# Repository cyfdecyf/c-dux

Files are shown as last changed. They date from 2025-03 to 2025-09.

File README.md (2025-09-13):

# C. Dux Keyboard

C. Dux front               |  C. Dux back
:-------------------------:|:-------------------------:
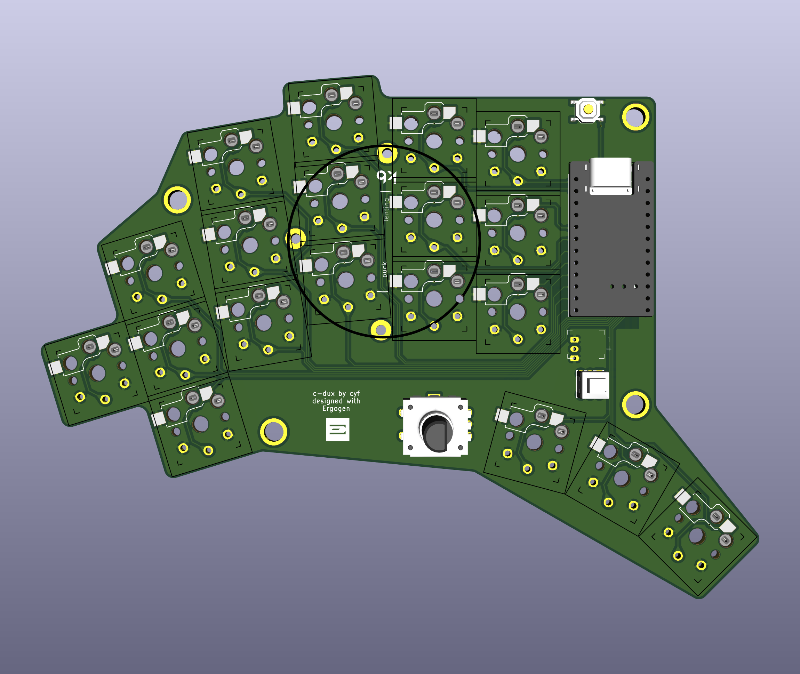
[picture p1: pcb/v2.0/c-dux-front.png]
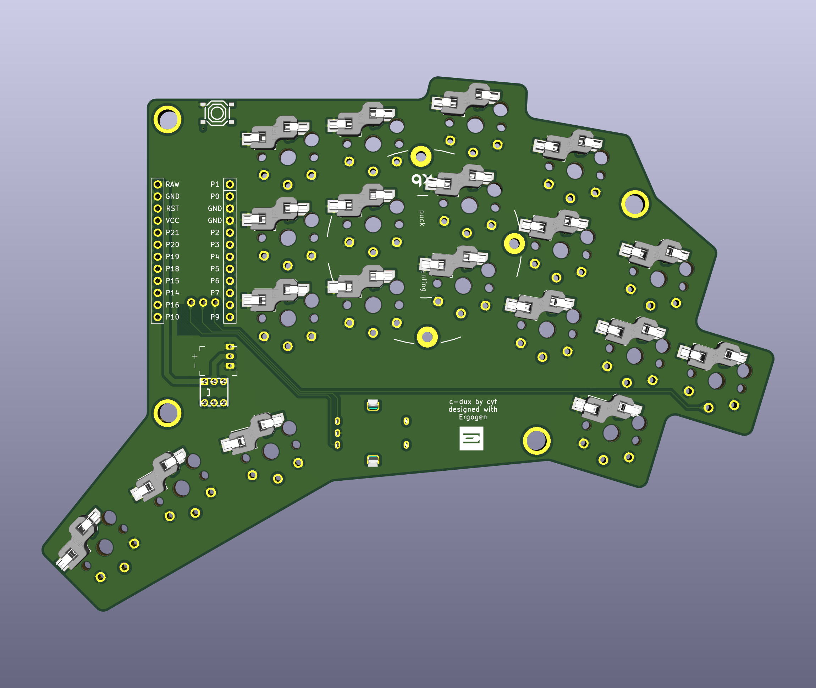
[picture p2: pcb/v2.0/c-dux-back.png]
  |  

**C. Dux** is a 38-key split wireless keyboard inspired by
[**rae-dux**](https://github.com/andrewjrae/rae-dux) and
[**Architeuthis Dux**](https://github.com/tapioki/cephalopoda/tree/main/Architeuthis%20dux) (A. Dux).

## Features

- **Split Design**: 38-key, mainly 3x5 column-staggered layout, **3 thumb keys and 1 extra pinky key**
- **Choc v1 switch, optional hot-swap sockets**
- **Uses ZMK firmware**
- **Rotary encoder** placed near thumb, easy to reach
- **Diodless Reversible PCB**: Single PCB design that can be used for both left and right halves

Note: I did not consider designing a case as I use the keyboard with nacked PCB.
So it's better to use leadless PCB and solder. I find SAC305 solder (with 380-degree solder iron)
is a little harder to use compared to Tin-Lead 63/37 solder (with 280-degree solder iron),
but not too much. 

## Differences with rae-dux:

- **One extra key for little finger**
  - C. Dux [v1 uses 36-key](./pcb/v1.0/c-dux-front.png), but as a long time Vim user who uses Capslock as Esc, I
    missed the efficiency of pressing Esc with pinky. So I added the extra pinky key.
- **Supports EC11/EC12 rotary encoder**
  - I use the left encoder for left, right arrow keys, the right one for up and
    down. With layer switching, they are also used for page up/down, alt f/b (in
    shell), ctrl-tab/ctrl-shift-tab.
- **Using [ProMicro NRF52840](https://www.nologo.tech/product/otherboard/NRF52840.html) as controller**
  - I choose diodeless design to make things simple. With vanilla ProMicro's 18 GPIO pins, I
    can only build a 36-key keyboard.
  - Both [nice!nano](https://nicekeyboards.com/nice-nano/) and ProMicro NRF52840 provides 3 extra pins,
    which allows adding rotary encoder and one extra key. But the physical position for the 3 extra
    pins on those two controllers are not the same, so they are not fully compatible.
- **With mounting holes to for [Tenting Puck](https://splitkb.com/products/tenting-puck)**
  - Using only 3 holes, took the design from A. Dux
- **M4 holes for other mounting options**

The keyboard layout and PCB is generated using [Ergogen](https://github.com/ergogen/ergogen) v4.
Traces are added manually in KiCAD 8.
I learned how to use Ergogen form [FlatFootFox](https://flatfootfox.com/)'s
[Let's Design A Keyboard With Ergogen v4](https://flatfootfox.com/ergogen-introduction/) series articles,
highly recommended!

## Configurations

Refer to my [zmk-config](https://github.com/cyfdecyf/zmk-config) repo. I do
local build, github workflow is not tested.

Some combos are inspired by [Glove80 TailorKey](https://sites.google.com/view/keyboards/glove80_tailorkey).
(I own one [Moergo's Glove80](https://www.moergo.com/). It's a great keyboard. I
started using home-row mod with Glove80.)

## PCB files

Here's [v2.0 PCB gerbers file](./pcb/v2.0/c-dux-gerbers.zip). You can download
the file and place order from JLC.
I made a few fixes for problems found after I got the PCB from JLC, so it's not
exactly the same file I've used but should work without problems.

## Tips for using Ergogen with KiCAD

For non-key footprints (power/reset switches, etc.), my workflow is:

1. Generate the footprint in PCB with Ergogen at arbitrary position
2. Place the footprint in KiCAD with mouse
3. Use KiCAD ruler to find relative position to some key
4. Update the footprint position in Ergogen yaml file

## My own build

As I suffer from RSI, I choose the 20g pink Choc v1 switches (which is the lightest switches I know).
For keycaps, I find the 3D printed saddle variant of 
[KLP-Lame-Keycaps](https://github.com/braindefender/KLP-Lame-Keycaps) quite pleasant to use. The keycap
curve makes it easy to press the up & down rows, and helps a lot to position fingers on the home row.

PCBs are ordered from JLC. [Power](https://item.szlcsc.com/2774931.html) and
[reset](https://item.szlcsc.com/299976.html) switch are from LCSC.

### C. Dux v2

I got the idea of mouting keyboard on desk and let hands go twards the ground from
[Ben Vallack](https://www.youtube.com/@BenVallack)'s video
[The Perfect TENTING SOLUTION For Split Keyboards](https://www.youtube.com/watch?v=mT3TToFqqEU).
Check out Ben Vallack's channel if you are interested in ergonomic keyboards.

This is the most comfortable way for me to use a keyboard. **This position helps
a lot to relieve my RSI and I can work all day long without much pain in my forearm**.

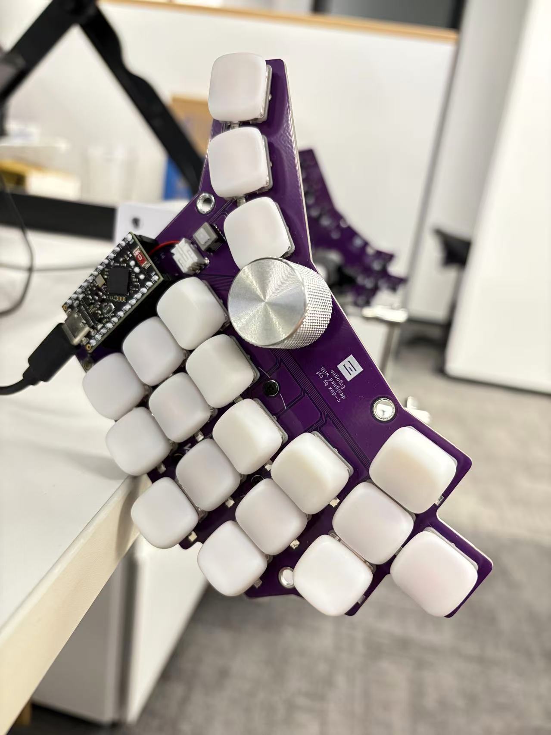
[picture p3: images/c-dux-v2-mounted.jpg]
C. Dux v2 mounted


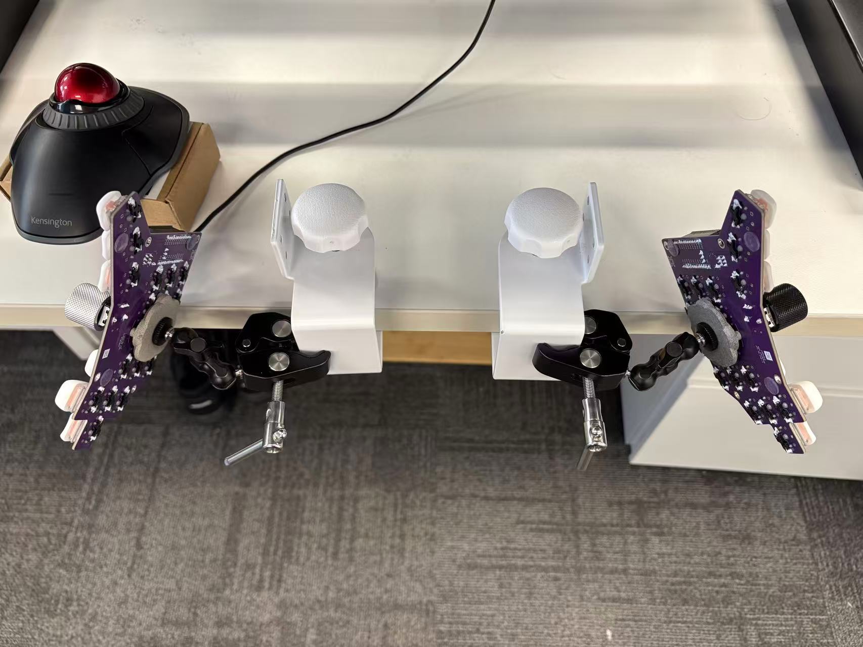
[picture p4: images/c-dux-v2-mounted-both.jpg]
C. Dux v2 mounted both


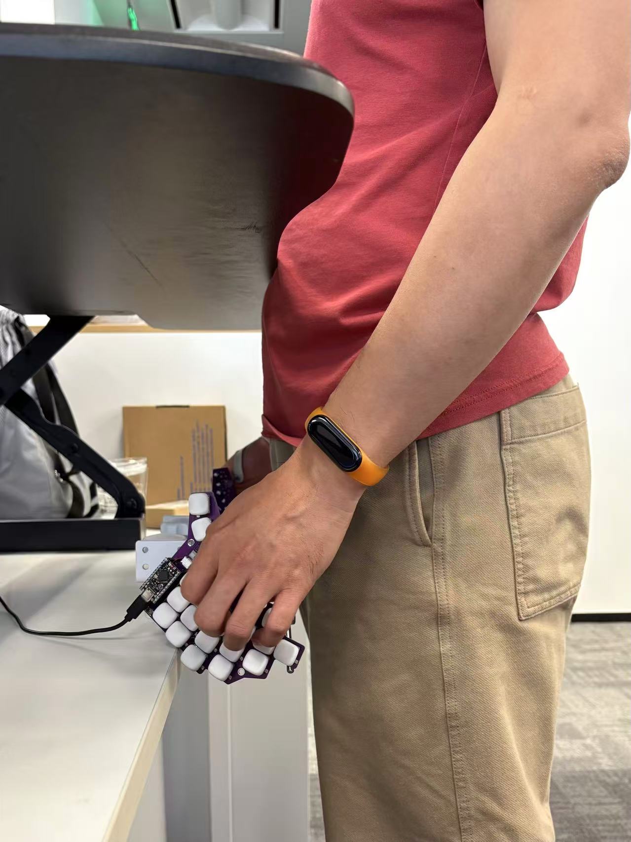
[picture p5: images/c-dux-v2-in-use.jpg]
C. Dux v2 in use


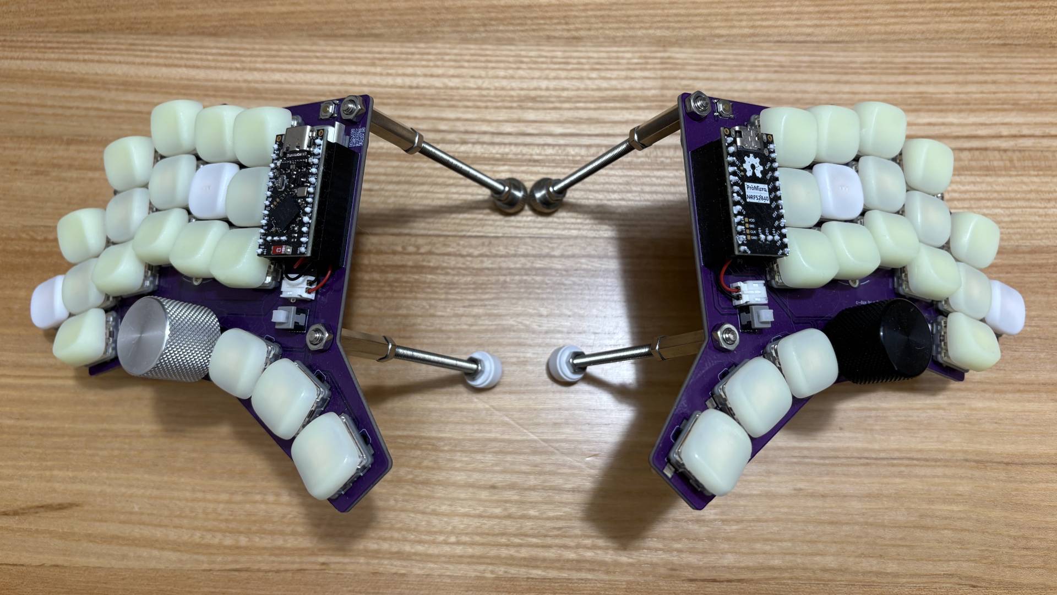
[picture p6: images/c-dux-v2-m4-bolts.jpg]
C. Dux v2 with M4 threaded bolts


### C. Dux v1

This is my first attempt to build a keyboard. The rotary encoder is difficult to reach
which is the biggest mistake I made.

The keycap used in this version is Chosfox's
[CFX](https://chosfox.com/products/chocfox-cfx-choc-keycaps) keycap.
(Search for "哈狐 Chosfox" on Taobao if you live in China.)
This keycap is not as smootch as Moergo's [MCC keycap](https://www.moergo.com/collections/mcc-keycaps),
but it's still quite good and is much cheaper. But as I like the curved keywell of Glove80,
I switched to KLP Lame keycaps later.

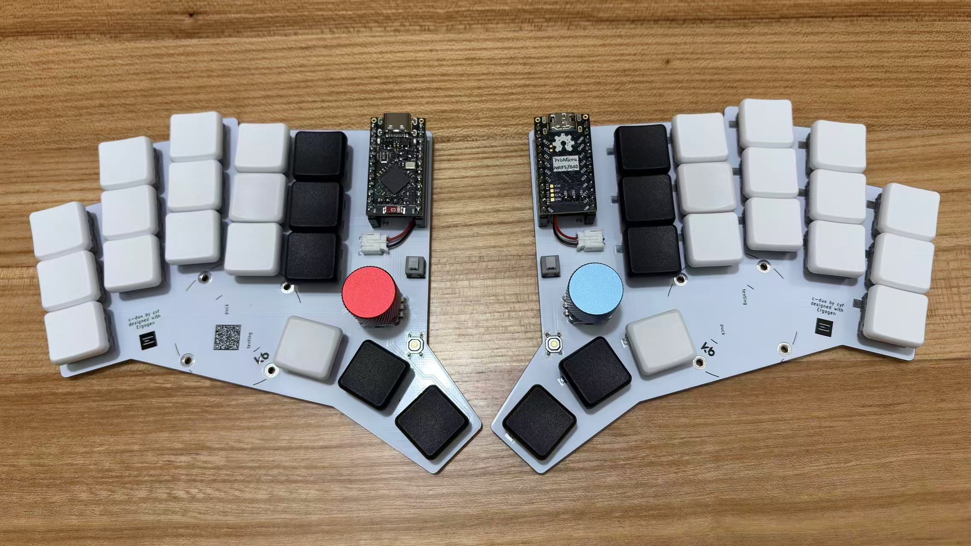
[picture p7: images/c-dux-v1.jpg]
C. Dux v1


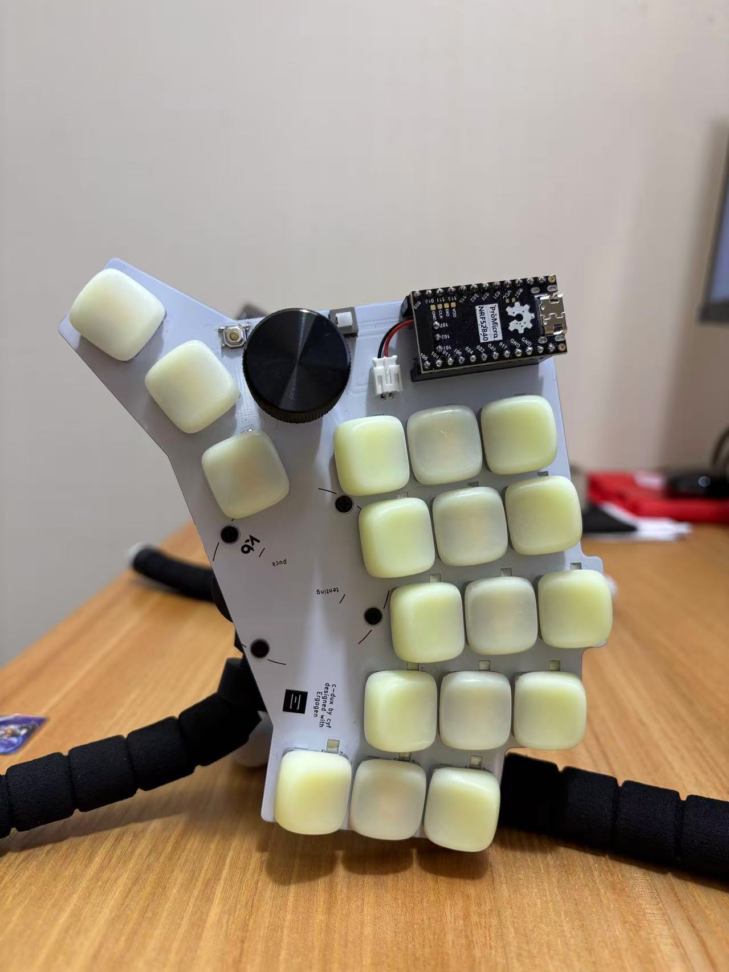
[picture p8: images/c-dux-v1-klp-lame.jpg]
C. Dux v1 with KLP Lame keycaps


## Future plans

I'm quite comfortable with C. Dux v2 and I'm not planning to build an improved version soon.
But I do plan to build a third keyboard for backup.

Here are a few things that I'd like to change:

- Decrease thumb key spacing
  - v2 decrease thumb key spacing compared to v1, but it's still wider
    compared to Glove80's upper thumber cluster
- Change hotswap socket outer hole diameter to 1.72mm
  - v1 uses 1.7mm which is too tight, v2 uses 1.74mm which is a bit loose
- Move rotary encoder a little up to make it easier to reach for index finger
- Remove teardrop for all GND pads to make solding easier
  - Even thermal reliefs teardrop still makes it harder to solder

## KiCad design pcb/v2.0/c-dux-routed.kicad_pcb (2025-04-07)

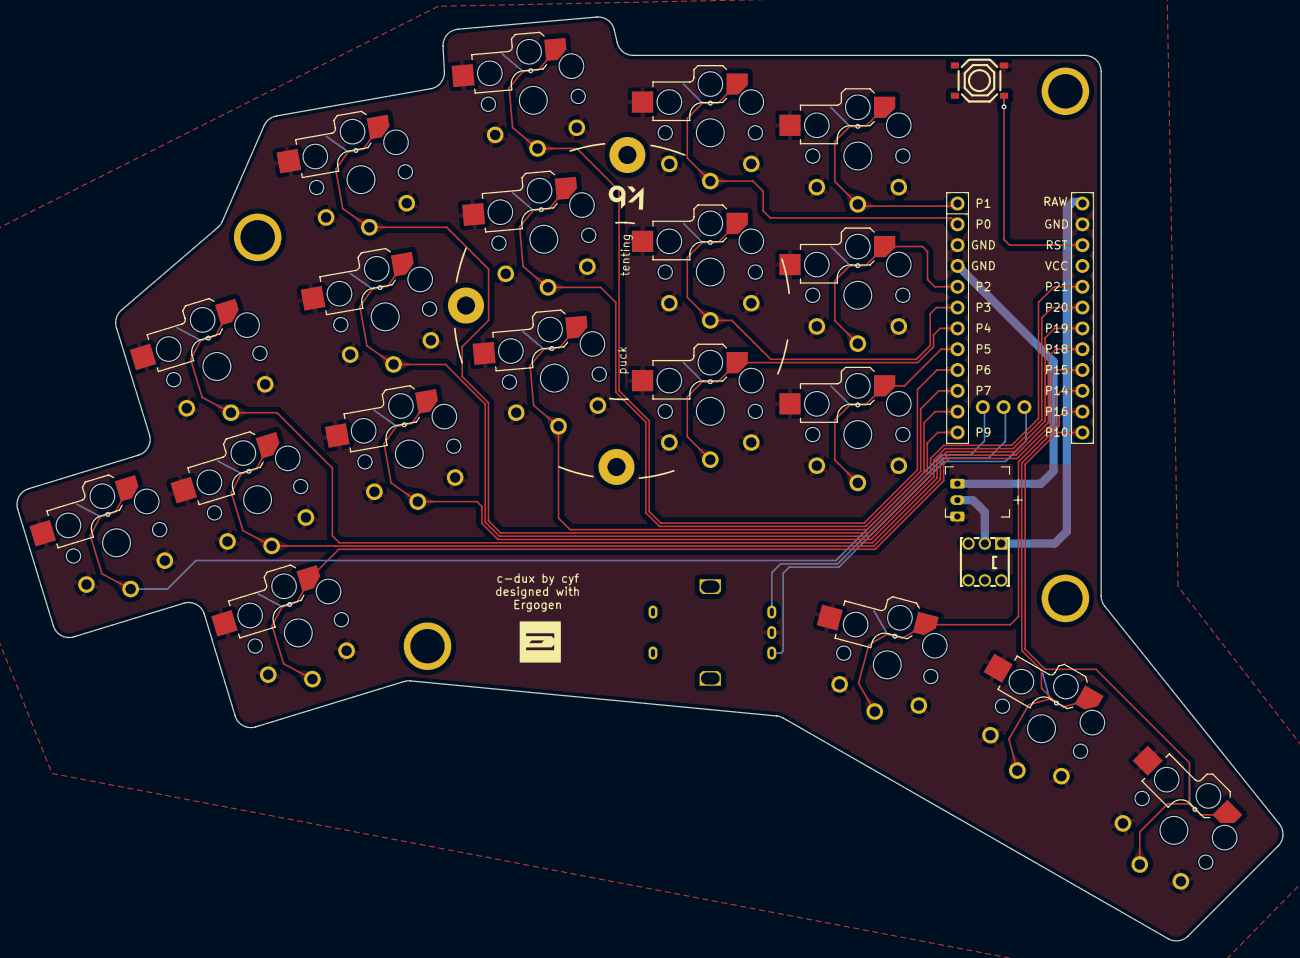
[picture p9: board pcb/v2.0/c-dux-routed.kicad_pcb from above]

Board: 2 copper layers, 154.5 x 112.8 mm, 30 parts (0 on the bottom side), 25 nets.

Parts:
H1, H2, H3, H4: mounting_hole_plated
JST1: battery_connector_jst_ph_2
LOGO1: utility_ergogen_logo
MCU1: mcu_supermini_nrf52840
RE1: rotary_encoder_ec11_ec12
S1, S2, S3, S4, S5, S6, S7, S8, S9, S10, S11, S12, S13, S14, S15, S16, S17, S18, S19: switch_choc_v1_v2
SW1: SW_Push_Lock; SW-TH_5.8ZSPT
SW2: SW-SMD_4P; SW-SMD_4P-L5.1-W5.1-P3.70-LS6.5-TL_H1.5
TP1: Tenting Puck, no hole; TentingPuck_NoHole

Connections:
BRAW: JST1.2, SW1.2
GND: JST1.1, JST1.3, MCU1.2, MCU1.21, MCU1.22, RE1.B, S1.1, S1.2, S2.1, S2.2, S3.1, S3.2, S4.1, S4.2, S5.1, S5.2, S6.1, S6.2, S7.1, S7.2, S8.1, S8.2, S9.1, S9.2, S10.1, S10.2, S11.1, S11.2, S12.1, S12.2, S13.1, S13.2, S14.1, S14.2, S15.1, S15.2, S16.1, S16.2, S17.1, S17.2, S18.1, S18.2, S19.1, S19.2, SW2.3
P0: MCU1.23, S13.1, S13.2
P1: MCU1.24, S16.1, S16.2
P2: MCU1.20, S15.1, S15.2
P3: MCU1.19, S12.1, S12.2
P4: MCU1.18, S11.1, S11.2
P5: MCU1.17, S14.1, S14.2
P6: MCU1.16, S10.1, S10.2
P7: MCU1.15, S9.1, S9.2
P8: MCU1.14, S8.1, S8.2
P9: MCU1.13, S7.1, S7.2
P10: MCU1.12, S19.1, S19.2
P14: MCU1.10, S17.1, S17.2
P15: MCU1.9, S2.1, S2.2
P16: MCU1.11, S18.1, S18.2
P18: MCU1.8, S3.1, S3.2
P19: MCU1.7, S4.1, S4.2
P20: MCU1.6, S5.1, S5.2
P21: MCU1.5, S6.1, S6.2
P101: MCU1.25, S1.1, S1.2
P102: MCU1.26, RE1.A
P107: MCU1.27, RE1.C
RAW: MCU1.1, SW1.1
RST: MCU1.3, SW2.1

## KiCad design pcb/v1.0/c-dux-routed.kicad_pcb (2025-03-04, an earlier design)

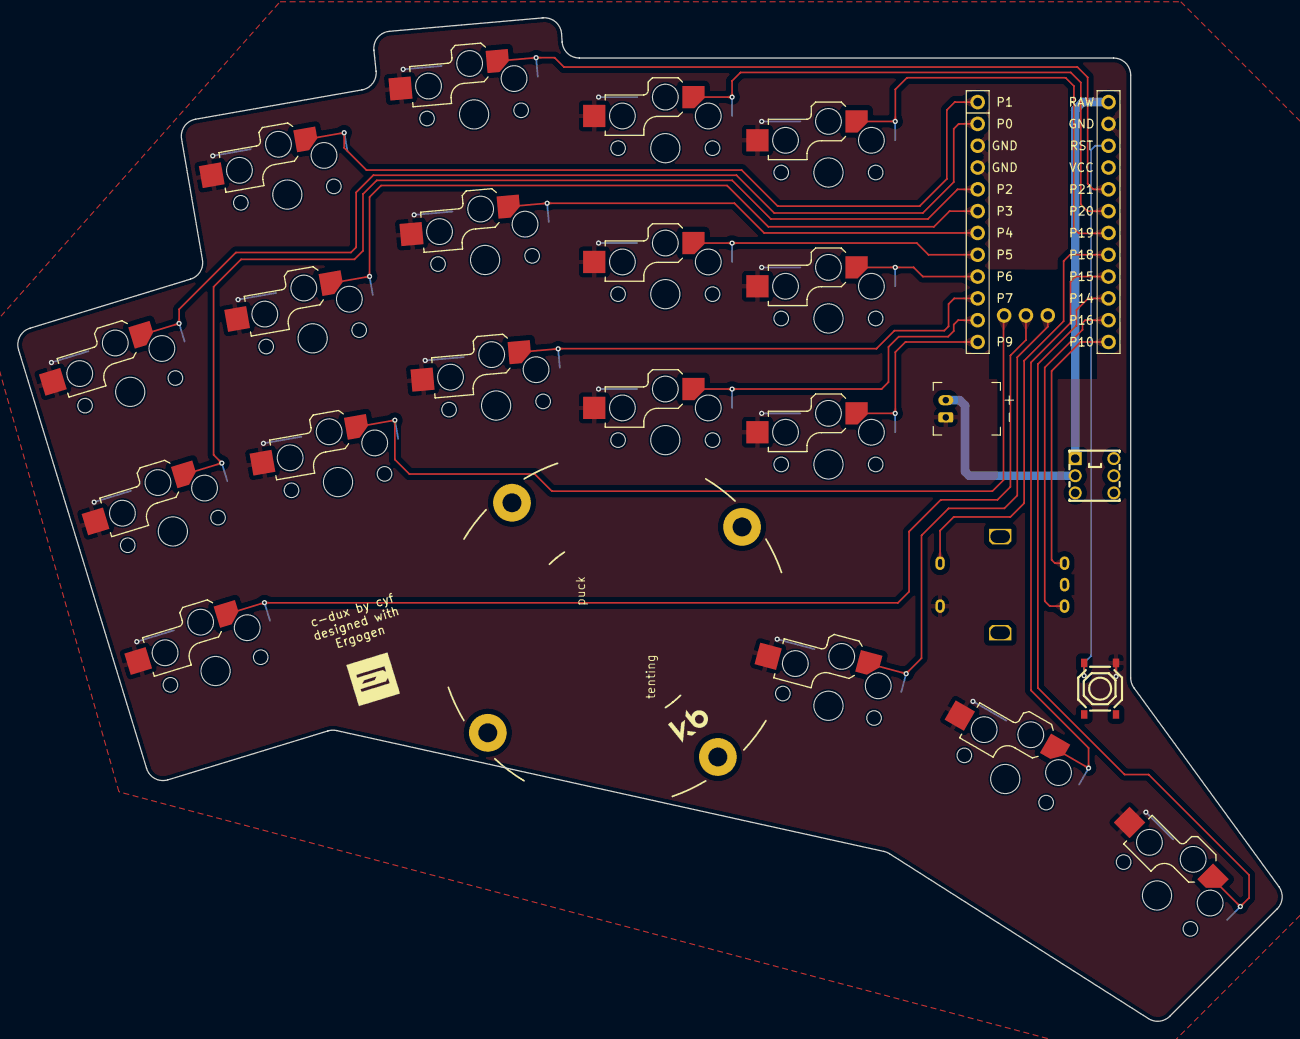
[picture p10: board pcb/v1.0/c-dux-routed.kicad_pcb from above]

Board: 2 copper layers, 147.3 x 116.9 mm, 25 parts (0 on the bottom side), 25 nets.

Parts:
JST1: battery_connector_jst_ph_2
LOGO1: utility_ergogen_logo
MCU1: mcu_supermini_nrf52840
RE1: rotary_encoder_ec11_ec12
S1, S2, S3, S4, S5, S6, S7, S8, S9, S10, S11, S12, S13, S14, S15, S16, S17, S18: switch_choc_v1_v2
SW1: SW_Push_Lock; SW-TH_5.8ZSPT
SW2: SW-SMD_4P; SW-SMD_4P-L5.1-W5.1-P3.70-LS6.5-TL_H1.5
TP1: Tenting Puck, no hole; TentingPuck_NoHole

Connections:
BRAW: JST1.2, SW1.2
GND: JST1.1, MCU1.2, MCU1.21, MCU1.22, RE1.B, RE1.S1, S1.1, S1.2, S2.1, S2.2, S3.1, S3.2, S4.1, S4.2, S5.1, S5.2, S6.1, S6.2, S7.1, S7.2, S8.1, S8.2, S9.1, S9.2, S10.1, S10.2, S11.1, S11.2, S12.1, S12.2, S13.1, S13.2, S14.1, S14.2, S15.1, S15.2, S16.1, S16.2, S17.1, S17.2, S18.1, S18.2, SW2.1
P0: MCU1.23, S3.1, S3.2
P1: MCU1.24, S6.1, S6.2
P2: MCU1.20, S2.1, S2.2
P3: MCU1.19, S5.1, S5.2
P4: MCU1.18, S8.1, S8.2
P5: MCU1.17, S11.1, S11.2
P6: MCU1.16, S14.1, S14.2
P7: MCU1.15, S7.1, S7.2
P8: MCU1.14, S10.1, S10.2
P9: MCU1.13, S13.1, S13.2
P10: MCU1.12, RE1.A
P14: MCU1.10, S18.1, S18.2
P15: MCU1.9, S17.1, S17.2
P16: MCU1.11, RE1.C
P18: MCU1.8, RE1.S2
P19: MCU1.7, S15.1, S15.2
P20: MCU1.6, S12.1, S12.2
P21: MCU1.5, S9.1, S9.2
P101: MCU1.25, S4.1, S4.2
P102: MCU1.26, S1.1, S1.2
P107: MCU1.27, S16.1, S16.2
RAW: MCU1.1, SW1.1
RST: MCU1.3, SW2.3

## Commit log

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2025-01-31 outline: add jst_bat, reset & power button, rotary encoder.
2025-02-01 Remove unnecessary footprint def in points section.
2025-02-07 pcb: initial add.
    Add hotswap socket, MCU, JST PH 2.0 connector, rotary encoder.
2025-02-07 footprint: add self lock switch from LCSC C2681588.
2025-02-07 pcb: add power switch.
2025-02-07 footprint: add momentary switch from LCSC C318884.
2025-02-07 pcb: add reset button.
2025-02-07 Make inter top cut edge same height with index top.
    This allows moving power & reset button up thus gives more space for rotary encoder.
2025-02-07 footprint: add tenting pack.
2025-02-07 pcb: add tenting puck.
2025-02-07 pcb: add 3d model for rotary encoder.
2025-02-07 pcb: add ergogen logo and c-dux text.
2025-02-09 pcb: use 1.7mm diameter for choc v1 socket outer stabilizer.
2025-02-10 chore(pcb): move rotary section below power button.
2025-02-10 pcb: move tenting puck a little down.
2025-02-10 pcb: mcu disable reverse mount.
2025-02-10 pcb: change net connection.
2025-02-11 Add Ergogen generated KiCAD files.
    [c-dux.kicad_pcb]
2025-02-11 kicad: initial routing.
    [c-dux-routed.kicad_pcb]
2025-02-11 pcb: update layout to match routed board.
2025-02-11 kicad: update ergogen generated pcb.
    [c-dux.kicad_pcb]
2025-02-11 kicad: finish routing.
    With some manual placement change after routing almost done.
    [c-dux-routed.kicad_pcb]
2025-02-12 kicad: fill copper zone for both sides, add tear drops.
    [c-dux-routed.kicad_pcb]
2025-02-12 kicad: manually remove unnecessary GND line on F.cu layer.
    After copper filling for F.cu, GND lines for choc hotswap socket become
    unnecessary and they have a very small gap with copper filling
    connection to PTH. Thus manually remove them to avoid potential
    problems.
    The problem could be fixed by changing ceoloide/switch_choc_v1_v2.js to
    add some offset for the via hole.
    [c-dux-routed.kicad_pcb]
2025-03-04 kicad: manually fix problems found after PCB production.
    1. EC11 through hole should have copper on both layer.
    2. JST connector also have silkscreen on back side.
    [c-dux-routed.kicad_pcb]
2025-03-05 submodule: use my own fork of ergogen-footprints with improvements.
2025-03-05 ergogen: include silkscreen on both sides for battery connector.
2025-03-07 Add all PCB related output to pcb/v1.0 folder.
    [c-dux-routed.kicad_pcb, c-dux.kicad_pcb]
2025-03-16 pcb: increase choc v1 outer stabilizers diameter to 1.74mm.
2025-03-16 pcb: choc v1 enable solder.
    So that hotswap socket is optional.
2025-03-16 pcb: reduce index & inner column spread.
2025-03-16 chore: retab footprint js files.
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2025-03-29 pcb: jst ph 2 connector use 3 through holes.
2025-03-29 pcb: choc switch does not include trace for GND pads.
2025-03-29 outline: keep only keys and mcu.
    For other components, let's just place them in KiCAD
    and sync back position in pcb section.
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2025-03-29 footprint(tenking_puck): add option to use only 3 holes.
2025-03-29 pcb: tenting puck use only three holes, change position.
2025-03-29 pcb: move rotary encoder to beside thumb home key.
2025-03-29 pcb: rotary encoder only use A, B line.
2025-03-29 pcb: move mcu closer to key, lower for 30mm battery.
2025-03-29 pcb: move battery, reset, power button location.
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2025-03-30 pcb: move tenting puck to center.
    Learn from Architeuthis dux's placement of tenting puck.
2025-03-31 pcb: move mcu, etc. left, make PCB more compact.
2025-03-31 pcb: give mouting hole 8mm diameter for hex nut.
    Move mcu down to give more room for 701230 LiPo battary (actual length is 32mm).
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2025-04-02 pcb: fix tenting puck overlapping with hotswap pd.
    Discovered running DRC check for routing.
2025-04-02 pcb: move mcu 0.2mm left.
    So that copper fill can cover mcu edge and connect to GND pin.
2025-04-02 pcb: change power button rotation for ease of routing.
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2025-04-02 pcb: move text to not overlap with trace.
2025-04-07 v2.0: add generated and routed KiCAD PCB files.
    [c-dux-routed.kicad_pcb, c-dux.kicad_pcb]
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2026-10-31 case/build123d: 初版立式支架(单体式)
    build123d 参数化垂直站立支架,合并 10 个早期迭代:
    - 底座-立板交接加强;降低键盘安装位、底座加宽
    - 安装朝向翻转,避开肋-柱干涉
    - home row 角度旋转孔组(4 组收敛为 3 组),高度规则=角点离桌间隙 + 2 mm
    - 去掉浮雕 logo;硬币配重槽默认关闭,底座后部加深使其齐平
    - 后仰侧底座加长(base_rear 78→100)
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2026-10-31 case/build123d: 拆分共享底座 + 按后仰角立板,移除 OpenSCAD 旧方案
    - 结构两件式:共享底座(只打印一次)+ 按后仰角的立板,榫键 + 2×M4 从底面拧接
    - 接头螺钉翻面:螺母沉在靴座,从下方拧入
    - 导出默认只出 STL,--step 才附 STEP
    - 底座收窄到与立板齐平(base_side 24→16)
    - 删除 case/scad OpenSCAD 初版,文档并入 build123d README
2026-10-31 case/build123d: 安装孔组与底座定型 + 工程化
    - 接头键槽在靴座打通;安装收敛为单一孔组,立板按螺孔桌面投影定高
    - 底座瘦身降本(base_t 8→6、front 32→30、宽度齐平 132.5),boot 加高后伸抗夹持载荷
    - 配合试块分两件导出 STL
    - 背板在肋带以上向柱位包络收腰
    - build123d 升级 0.13.0;新增底座尺寸示意图脚本 base_dims_diagram.py
    - 根 README 补 Bambu Lab H2C 打印备注
2026-10-31 case/build123d: 打印性精修(无桥沉孔、收腰、--flange)
    - 胶垫/螺钉头沉孔改无桥设计;删除过时的键槽搭桥说明
    - 背板减重孔先加后删,保留实心;立板底带与底座齐平,外侧柱局部凸台并倒圆肩
    - --show 只推送 OCP 预览不泄漏噪声;flush 侧封口防零宽切割
    - 立板下前缘倒角;新增 --flange 易剥离贴床裙边
    - 默认 tilt 30 / set-angles −35;boot 后移 +8 mm,双肋加宽加高
2026-10-31 docs: stand.py design handbook for takeover
    docs/stand-design.md documents what the build123d README intentionally
    does not: the three coordinate frames and their mappings, the main()
    data flow, a responsibility map of every function, the solver
    algorithms (_solve_sets, _auto_ribs, _taper_outline), the boolean
    build order of each part, tuning knobs vs load-bearing constants, the
    support-free / free-standing / 0.4 mm tolerance invariants, and the
    audit tooling with current baseline numbers.
    Also brings the two audit scripts into the repo (overhang_report.py
    was untracked; layer_float_audit.py is the per-layer float audit the
    doc references) and links the handbook from AGENTS.md.
2026-10-31 case/build123d: 夹持方案重构——背夹 PCB(3 自攻 + 1 承载柱)
    从正面压紧改为从背后夹持 PCB,键盘整体下降约 29 mm。合并 24 个迭代:
    - 3 颗夹持自攻 + 1 根承载柱,共 4 个紧固点,弃埋藏式螺母沉孔;最低柱自攻固定
    - 以真实 PCB 板框为约束,孔组下降 28 mm;为埋藏螺母开检修窗后整体抬至 drop 20
    - 立板顶角按用户手绘修形;boot 内收 2 mm,前缘多轮调整后与立板背面齐平
    - 板底带收进靴座足迹,无侧向凸出;肋与凸台重新锚回背板,消除分离鳍片
    - 顶轮廓改为喇叭足外 2 mm 的两段直线;左顶角切深加深并修半平面切割器折叠
    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
2026-10-31 case/build123d: 几何收尾与默认角定型(−40→−45)
    - 默认安装角 −40°(修复低侧柱触发收腰台阶),后调 −45°(tilt 30 不变)
    - 靴座前伸埋唇填平底面台面,自攻底孔 Ø3.4→Ø3.8;前立面改为立板前表面自然延伸到底
    - 恢复最低柱 Ø15 喇叭口,靴座斜面承载越缘足环;凸台肩部改 45° 直线切割并与顶角切割线对称
    - 左螺钉内侧回退短肋、补齐左侧加强;底座进深 130→110(前 25/后 85)
    - 顶角切割线四端点倒 r3.5;螺母沉孔删收口唇、跨面 7.4→7.2;榫键加高至靴座全高 8、沉头 Ø8→7.6
    - 肋根截面优化:加厚 14、根深 26、顶截平、接缝倒圆
    - AGENTS.md:提交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
2026-10-31 case/build123d: 收录底座分析与验证脚本,AGENTS.md 记录用法
    新增:key_layout_check.py(各角度安装后键高排序,选旋转方向)、
    keyboard_clearance_check.py(键盘代理 vs 底座/立板/靴座布尔干涉+间隙,
    --json 导出绘图数据)、pcb_rotation_figure.py(旋转前后对比图:
    平放/安装正视+侧视,含水平面、键位与角点朝向标注);
    一并纳入此前未跟踪的 check_pcb_alignment.py(gerber↔KiCad↔stand
    孔位四方核对)。
    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
2026-10-31 case/build123d: 底座平底化与安装示意图更新
    - 删除底座胶垫定位凹槽,底面改平底,尺寸示意图同步
    - 图片移入 case/build123d/images/;新增 mounting_diagram.py 重画安装朝向图,更新 README 过时说明
2026-10-31 case/build123d: 最终定型(−53°、H3 Ø4.0、--pad-pockets、文件名编码角度)
    - clearance 脚本新增 H3 自攻容螺长检查;自攻底孔 Ø3.8→Ø4.0
    - 底座 4 角胶垫凹槽(切片支撑试验)+ padtest 支撑试块;凹槽改 --pad-pockets 开关默认平底,后恢复 6 个(4 角 + 前后中位)
    - 高度约束改为沿板面下滑余量 1.5 mm;安装角按照片实测 −45→−53°,drop 33→35.5 重绑下滑余量
    - 立板/装配预览/fit 文件名编码安装角;修正立板左右手标注
2026-10-31 README: 新增 3D 打印底座简介,修正过时的 case 说明
